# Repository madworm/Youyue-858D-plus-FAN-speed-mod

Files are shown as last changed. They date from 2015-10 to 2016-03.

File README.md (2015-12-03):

Youyue-858D+ FAN-speed mod:
===========================

LAYOUT FILES: Proper commutation-based speed detection for the BLDC fan.

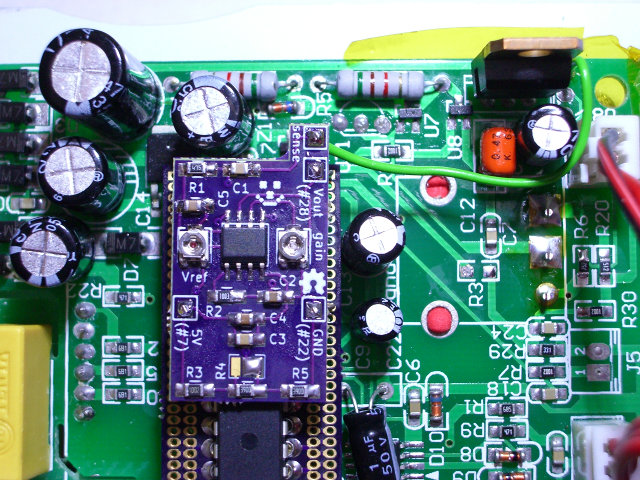
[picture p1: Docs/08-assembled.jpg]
Adapter front


Made to be used on top of this circuit board:

MCU-adapter-board [repository](https://github.com/madworm/Youyue-858D-plus-MCU-adapter)

Firmware [repository](https://github.com/madworm/Youyue-858D-plus)

---

Safety information / disclaimer:
================================
                                                                                                                                                             
Making any modifications to this device may cause you irreversible physical harm or worse.                                                                   
You do this at your own risk.                                                                                                                                
                                                                                                                                                             
There is a significant risk of lethal electrical shock, so if you still insist of doing so, make sure to                                                     
ALWAYS UNPLUG THE MAINS CABLE before dismantling the device. Check repeatedly.                                                                               
                                                                                                                                                             
If you have an isolation transformer - do use it.

---

Before having PC-boards made, please make sure you know about your manufacturer's peculiarities!
Especially drill-sizes and their tolerances may vary too much and give you trouble.

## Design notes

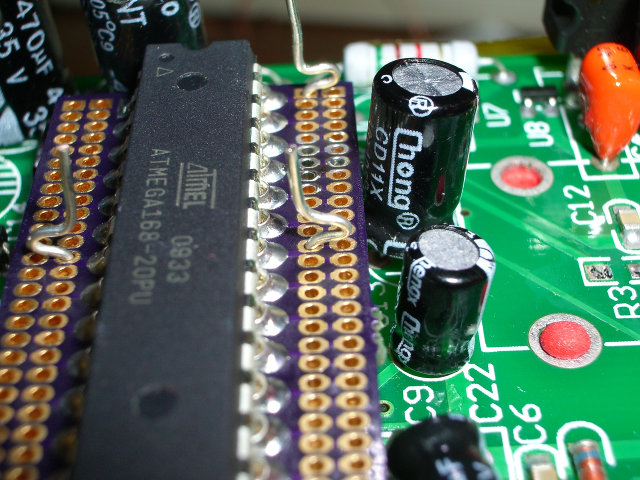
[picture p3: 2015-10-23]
Docs/05-spacers.jpg

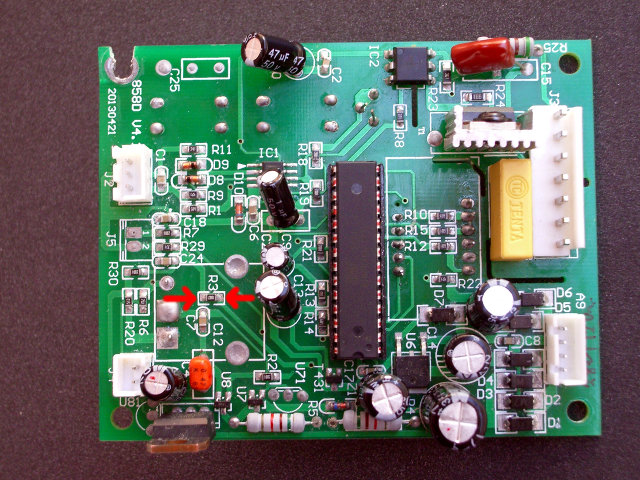
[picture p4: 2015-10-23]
Docs/04-remove-R3.jpg

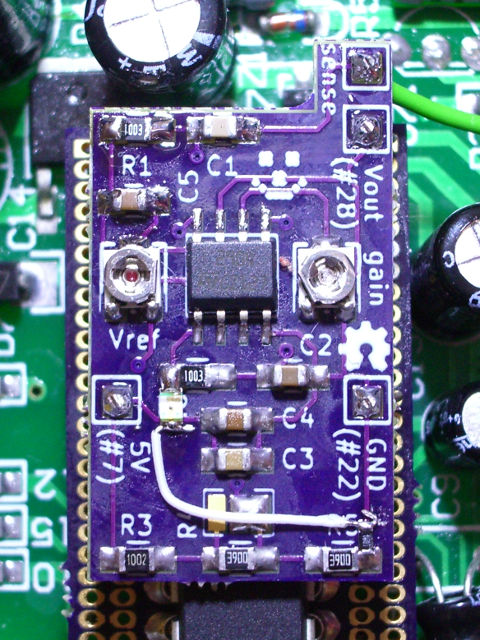
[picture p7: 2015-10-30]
Docs/12-LED-hack.jpg

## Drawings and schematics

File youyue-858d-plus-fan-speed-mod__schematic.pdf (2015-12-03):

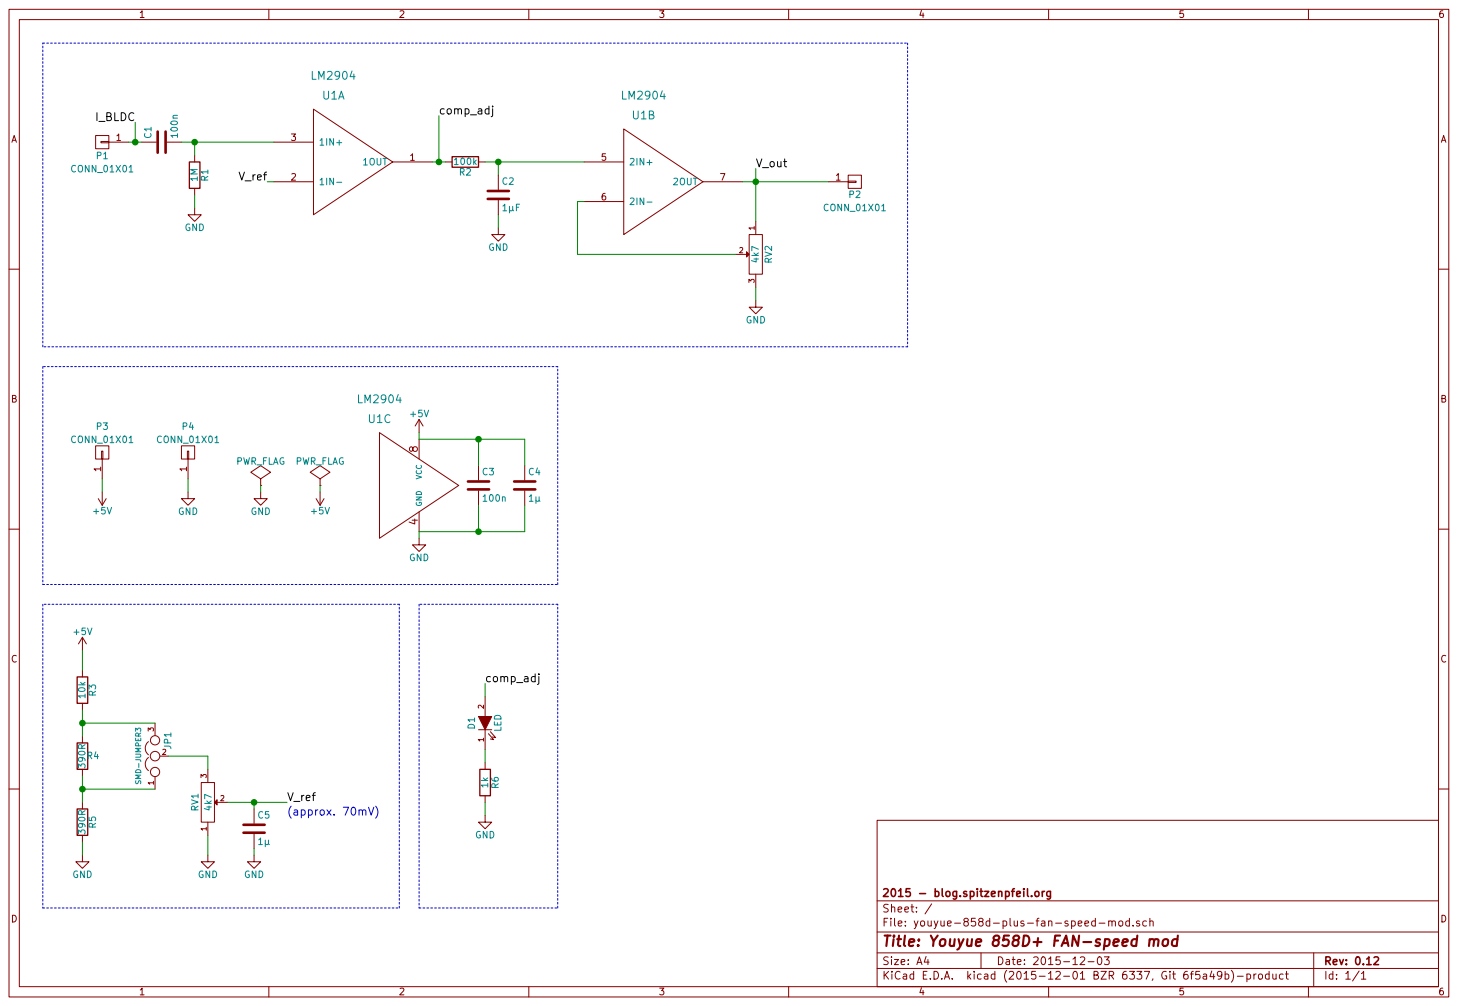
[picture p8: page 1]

File: youyue-858d-plus-fan-speed-mod.sch Sheet: / 2015 - blog.spitzenpfeil.org

Id: 1/1 Title: Youyue 858D+ FAN-speed mod

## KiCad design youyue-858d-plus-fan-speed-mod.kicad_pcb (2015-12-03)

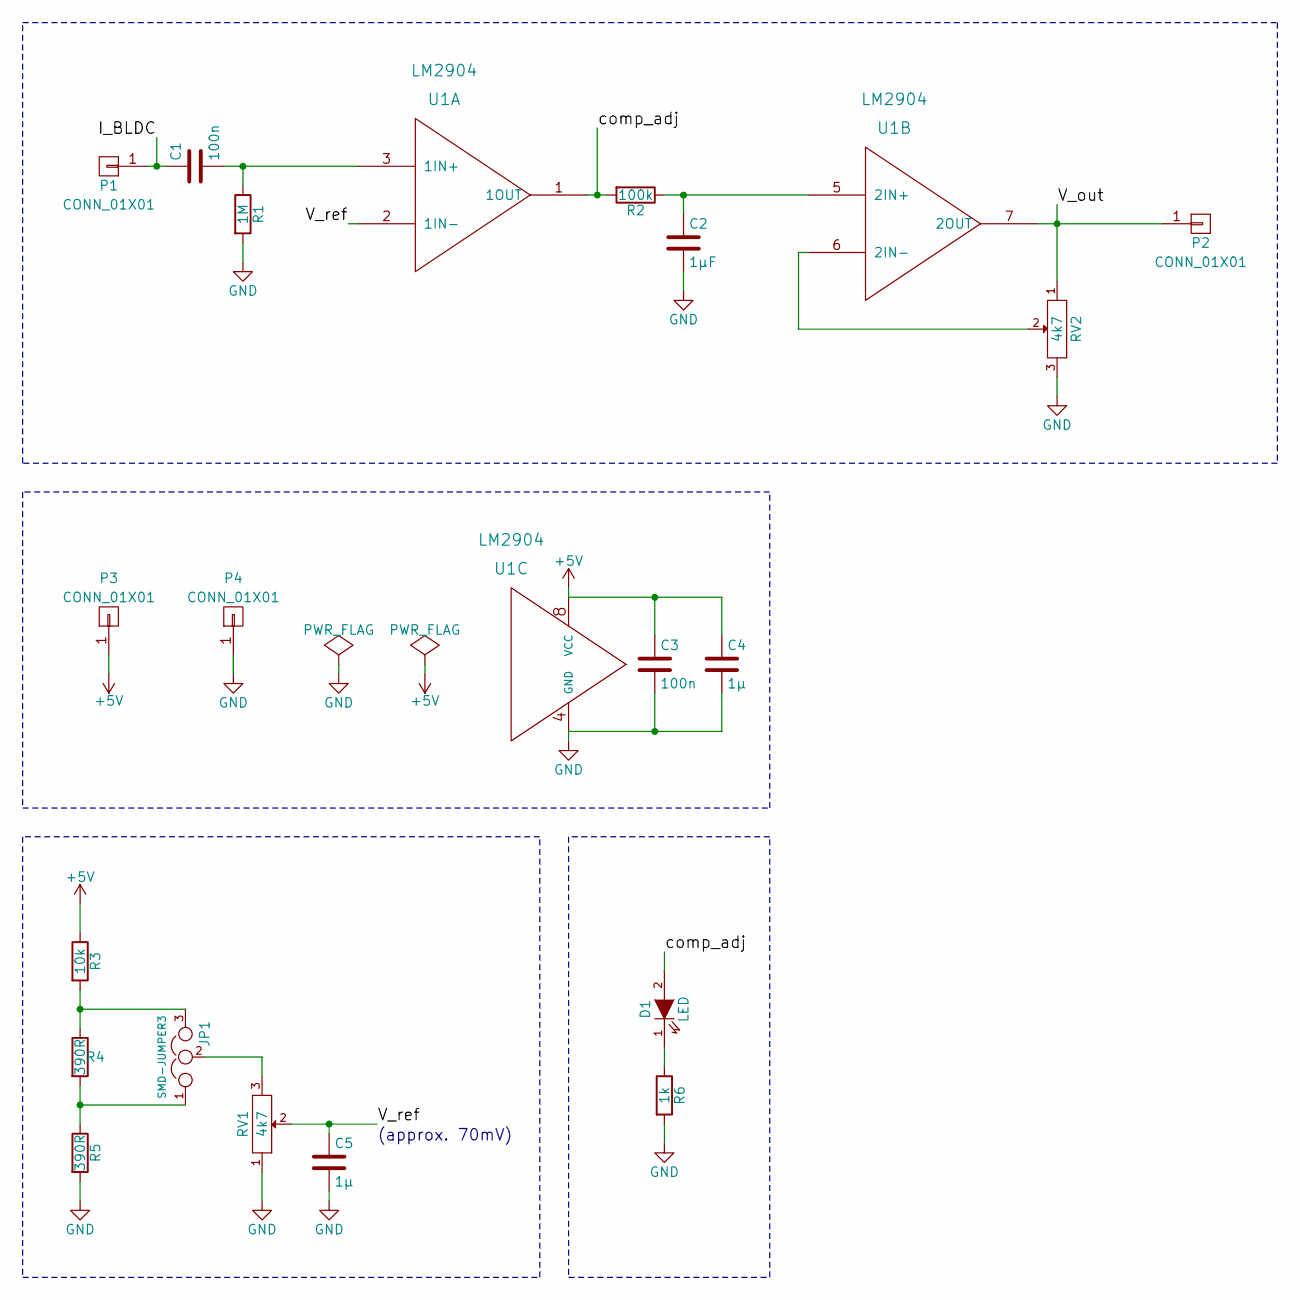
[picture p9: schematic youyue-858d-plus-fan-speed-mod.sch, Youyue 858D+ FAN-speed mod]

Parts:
C1, C3: 100n; C_0805_HandSoldering
C2: 1µF; C_0805_HandSoldering
C4, C5: 1µ; C_0805_HandSoldering
D1: LED; LED-0805
JP1: SMD-JUMPER3; SMD-solder-bridge-3pin
P1, P2, P3, P4: CONN_01X01; SIL-1
R1: 1M; R_0805_HandSoldering
R2: 100k; R_0805_HandSoldering
R3: 10k; R_0805_HandSoldering
R4, R5: 390R; R_0805_HandSoldering
R6: 1k; R_0805_HandSoldering
RV1, RV2: 4k7; MADW__TC33X-POT
U1: LM2904; SOIC-8-N

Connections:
+5V: C3.1, C4.1, P3.1, R3.1, U1.8 (VCC)
/I_BLDC: C1.1, P1.1
/V_out: P2.1, RV2.1, U1.7 (2OUT)
/V_ref: C5.1, RV1.2, U1.2 (1IN-)
/comp_adj: D1.2 (A), R2.2, U1.1 (1OUT)
GND: C2.2, C3.2, C4.2, C5.2, P4.1, R1.2, R5.2, R6.2, RV1.1, RV2.3, U1.4 (GND)
unnamed: C1.2, R1.1, U1.3 (1IN+)
unnamed: C2.1, R2.1, U1.5 (2IN+)
unnamed: D1.1 (K), R6.1
unnamed: JP1.1, R4.2, R5.1
unnamed: JP1.2, RV1.3
unnamed: JP1.3, R3.2, R4.1
unnamed: RV2.2, U1.6 (2IN-)

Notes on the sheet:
(approx. 70mV)

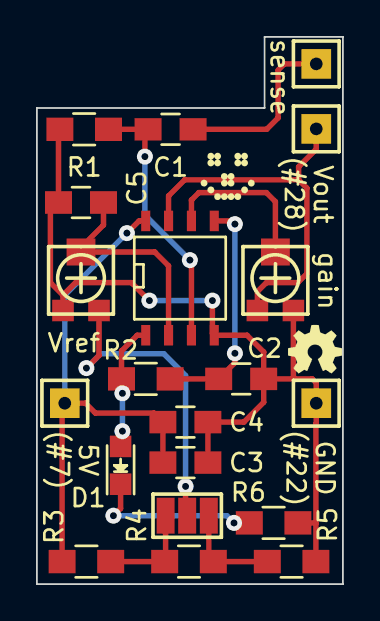
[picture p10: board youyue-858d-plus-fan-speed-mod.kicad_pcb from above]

Board: 2 copper layers, 17.0 x 30.4 mm, 20 parts (0 on the bottom side), 13 nets.

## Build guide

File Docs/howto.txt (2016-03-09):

SAFETY WARNING:
===============

The device You are about to modify has exposed 240V parts when the AC cord is plugged in.

Touching any of these parts may cause you to die (for real). This is final.

Be EXTREMELY careful when following the installation instructions below, or let someone
else with suitable qualifications do it.

Avoid making adjustments on a live circuit. If you have to, use an isolation-transformer
(one hand only).

I shall not be held responsible for any damages that may result from following
the steps below.

Installation:
=============

* !! UNPLUG the AC cord.

* !! REMOVE R3 (10k, SMD 0805) on the main circuit board BEFORE adding this mod. This disconnects
  the FAN voltage sensing (default state) going to PC5 (pin #28).

* Add a 1 Ohm current sense resistor as shown.

* Connect the mod-board to the ATmega168/328 as shown.

!! From here on, the circuitry needs to be powered again !!
!! This bears the risk of lethal electrical shock. Only use insulated tools (screwdrivers...) !!

* All voltages are measured in DC.

* Set Vref to about 70mV DC to get started, measured at the center-tab of the Vref-potentiometer
  (pointing towards R1).

* Where necessary, use a piece of paper, folded a couple of times, to stop the fan in fan-test mode.
  It should be very easy to stop.

* Ideally, use an oscilloscope to verify the signal after the comparator (LM2904 pin #1).
  It should show short square pulses for all fan speeds.

  Adjust Vref for best overall performance.

  If you don't have an oscilloscope, (temporarlity) connect an LED + resistor between pins #1 and #4
  on the LM2904 and adjust Vref to get a "faint glow". (Later boards have an on-board LED).

  If you use a True-RMS voltmeter, the voltages on pin #1 of the LM2904 should be about:

  Fan-speed :	stall	min	max
  V1 [mV]    :	290	375	640

* Check the signal after the RC low-pass filter (LM2904 pin #5): flat-line.

* Adjust the gain to acchieve an output voltage (LM2904 pin #7) of about 2.44V (Vout)
  when the fan spins at its highest speed. Make sure the opamp does not saturate.
  The voltage should show immediate response to fan-speed changes.

* Tweak all settings until you end up with these values in fan-test mode (up-button when power-on):

  Fan-speed :	stall	min	max
  Display   :	450	550	1000
  Vout [V]  :	1.10	1.34	2.44

* If everything appears to work, de-energize everything & reassemble.

* You will have to adjust the fan-speed configuration parameters & likely recompile.
  Consult the manual. Use the "fan-test" mode to find good low/high values.

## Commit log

2015-10-09 Moved sense-pin to free spot.
    [youyue-858d-plus-fan-speed-mod-B_Cu.gbl, youyue-858d-plus-fan-speed-mod-B_Mask.gbs, youyue-858d-plus-fan-speed-mod-B_SilkS.gbo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]
2015-10-23 Added schematic (PDF) + updated howto (2.5V).
2015-10-24 Added indicator LED for easy(er) comparator adjustment (no DSO).
    [youyue-858d-plus-fan-speed-mod.kicad_pcb, youyue-858d-plus-fan-speed-mod.sch]
2015-10-24 Renamed a bunch of files.
    [youyue-858d-plus-fan-speed-mod-B.Cu.gbl, youyue-858d-plus-fan-speed-mod-B.Mask.gbs, youyue-858d-plus-fan-speed-mod-B.SilkS.gbo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]
2015-10-24 Recreated gerber files.
    [youyue-858d-plus-fan-speed-mod-B.Cu.gbl, youyue-858d-plus-fan-speed-mod-B.Mask.gbs, youyue-858d-plus-fan-speed-mod-B.SilkS.gbo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]
2015-10-24 Updated 'Docs/howto.txt' regarding the LED.
2015-12-03 Fixed 'C2' in schematic: falsely marked as electrolytic.
    [youyue-858d-plus-fan-speed-mod.kicad_pcb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]
